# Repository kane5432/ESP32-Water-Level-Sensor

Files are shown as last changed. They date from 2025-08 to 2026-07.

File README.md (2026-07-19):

# Water Tank Level Monitor (ESPHome + Home Assistant)

If you found this project helpful, please consider supporting me:  

<a href="https://www.buymeacoffee.com/kanejarrats" target="_blank">Buy Me A Coffee</a>

This project uses an **ESP32‑C3** with an **ultrasonic sensor** to measure the water level in a tank, report the **fill percentage**, and **deep sleep** between readings to save power.  

It integrates with **Home Assistant**, storing the last known reading so you can still see the fill level even while the device is asleep.  

You can find the full blog post at https://jrattechworks.com/water-tank-level-sensor/

---

## Features
- Reads water tank level using an **AJ-SR04M** or similar ultrasonic sensor  
- Converts distance → **tank fill percentage**  
- **Deep sleep** between readings for extended battery life  
- **Persistent storage** in Home Assistant: keeps last known value when the ESP is offline  
- **OTA updates**: 2‑minute update window at each wake‑up for easy firmware flashing  

---

## Hardware
- **[ESP32‑C3 Super Mini](https://s.click.aliexpress.com/e/_c2uaIcnt)** (or compatible ESP32 board)  
- **[Ultrasonic Distance Sensor](https://s.click.aliexpress.com/e/_oocTPPV)** e.g. JSN‑SR04T or AJ-SR04M for waterproof applications)
- **[6V 1W Solar Panel](https://s.click.aliexpress.com/e/_onX79Zh)**
- **[TP4056 Charging Module](https://s.click.aliexpress.com/e/_omYIa87)**
- **[5v Boost Converter](https://s.click.aliexpress.com/e/_oBvVHe7)**
- **[470μF Capacitor](https://s.click.aliexpress.com/e/_oE1Fw4j)**
- **[1 kΩ + 2 kΩ resistors](https://s.click.aliexpress.com/e/_oFfpK9d)** (for voltage divider on echo pin)
- **[Wires](https://s.click.aliexpress.com/e/_oD4px7l) and a small enclosure** (optional but recommended)
- **[Soldering Iron](https://s.click.aliexpress.com/e/_c39TuVR5)**

## Wire the Ultrasonic Sensor to ESP32
- VCC → 5V (from boost converter)
- GND → GND
- Trigger → GPIO 3 (change in YAML if needed)
- Echo → Voltage divider (2 kΩ to Echo, 1 kΩ to GND, take signal from between resistors) → GPIO 2

### Why?
The sensor outputs 5V on Echo, but the ESP32 only tolerates 3.3V, the voltage divider drops it to a safe level.

## Wire the Power System
1. Solar panel → TP4056 input (IN+) & (IN–)
2. TP4056 output (BAT+ & BAT–) → Li‑ion battery
3. TP4056 output (BAT+ & BAT–) → Boost converter input
4. Boost converter output (5V & GND) → ESP32 5V pin and Ultrasonic sensor VCC
5. 470 µF capacitor across the boost converter output (helps prevent brown‑outs when ESP wakes up).

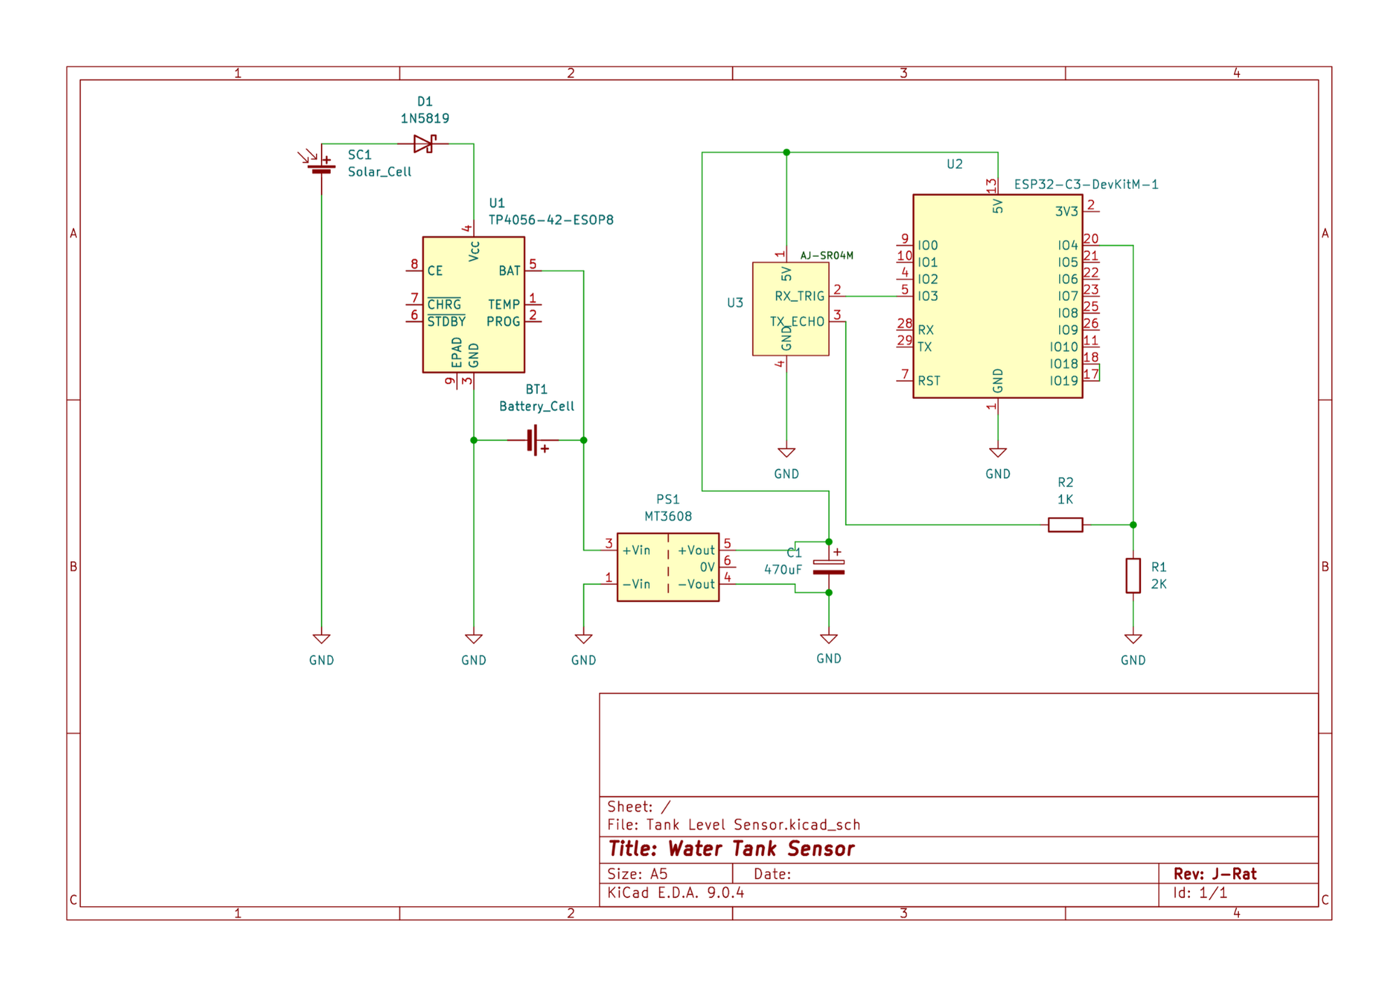
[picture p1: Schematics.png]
Schematic preview


---

## ESPHome Firmware
1. Copy the provided **`watertank-level.yaml`** file into your ESPHome directory (e.g., `esphome/watertank-level.yaml`).  
2. Replace the placeholders for Wi‑Fi credentials, API key, and OTA password.  
3. Adjust `max_distance` and `min_distance` in the YAML file to match your tank’s dimensions.  
4. Compile and flash the firmware to your ESP32 device using ESPHome.  

---

## Home Assistant Configuration
1. Open your `configuration.yaml`.  
2. Add the provided **input number** and **template sensor** sections for retaining the last known tank level.  
3. Restart Home Assistant to apply the changes.  

---

## Automation
1. Open your `automations.yaml`.  
2. Add the provided **automation** that updates the persistent tank level value whenever a new reading is received.  
3. Reload automations or restart Home Assistant.  

---

## Calibration
1. **Measure your tank’s depth when empty** → Set `max_distance` in the ESPHome file.  
2. **Measure the distance from the sensor to the water surface when full** → Set `min_distance`.  
3. **Flash the firmware** to your ESP device.  
4. **Monitor the ESPHome logs** to verify that readings are correct.  

---

## How it works
1. The ESP wakes up and connects to Wi‑Fi & Home Assistant API.  
2. It opens a **2‑minute OTA window** (can be changed in YAML) to allow firmware updates.  
3. The device takes a distance reading and converts it to a **fill percentage**.  
4. The reading is sent to Home Assistant.  
5. **If the reading succeeded:** the ESP goes into deep sleep for **1.5 hours**.  
6. **If the reading failed:** it retries after **1 minute**.

## Support this project
If you found this project helpful, you can support my work here:  



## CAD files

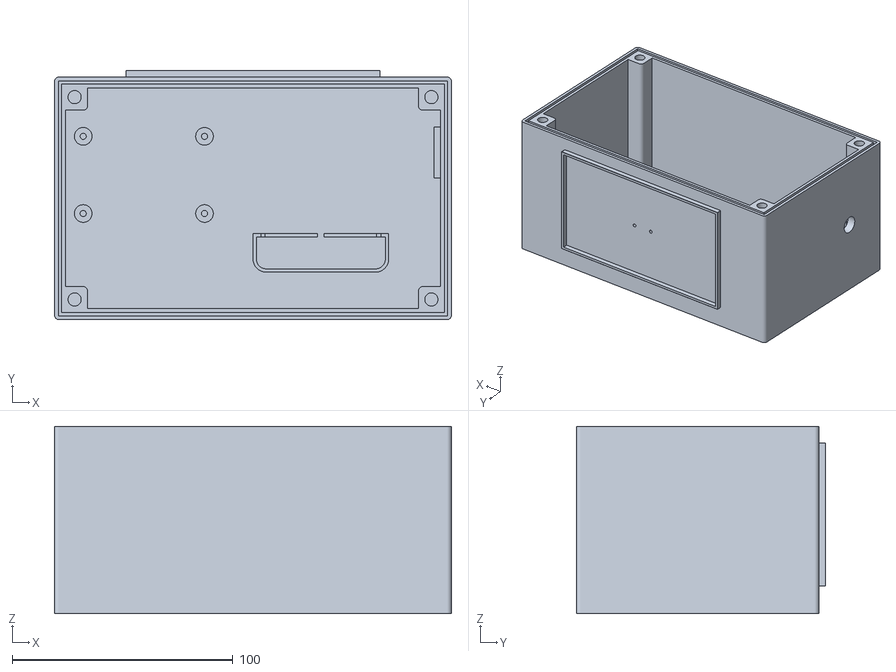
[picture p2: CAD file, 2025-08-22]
stl/WaterTankSensorBox-Body.stl
180.0 x 113.0 x 85.0

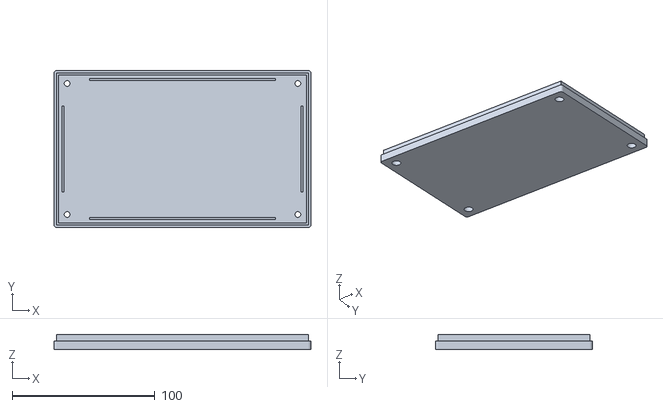
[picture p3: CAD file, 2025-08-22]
stl/WaterTankSensorBoxLid-Body.stl
180.0 x 110.0 x 10.7

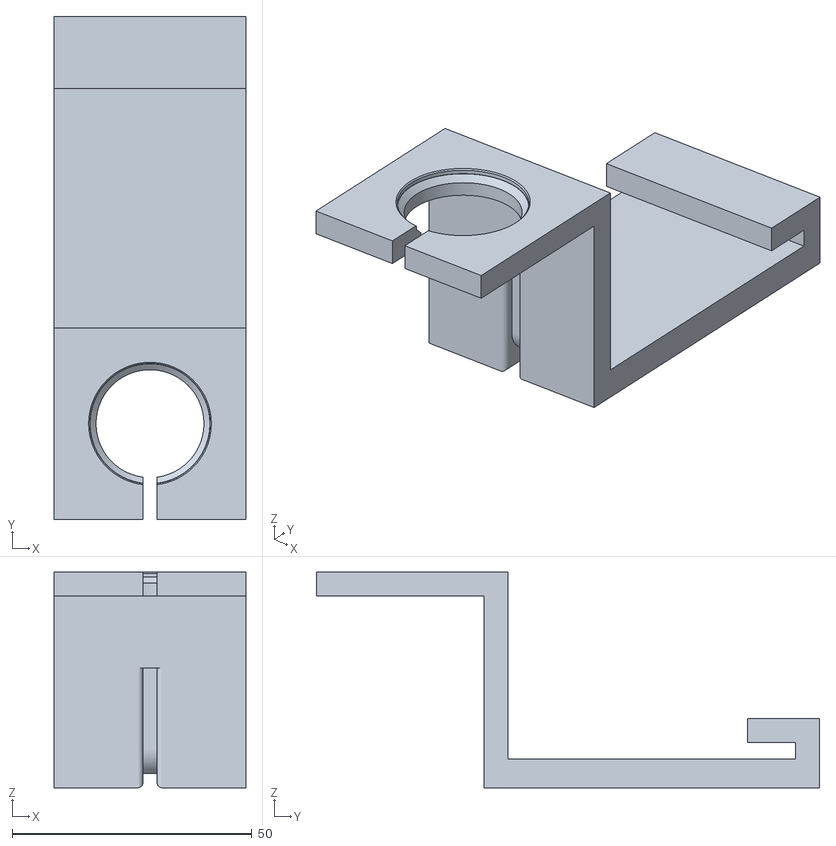
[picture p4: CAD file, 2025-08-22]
stl/UltrasonicHousing-BodySketch.stl
40.0 x 105.0 x 45.0

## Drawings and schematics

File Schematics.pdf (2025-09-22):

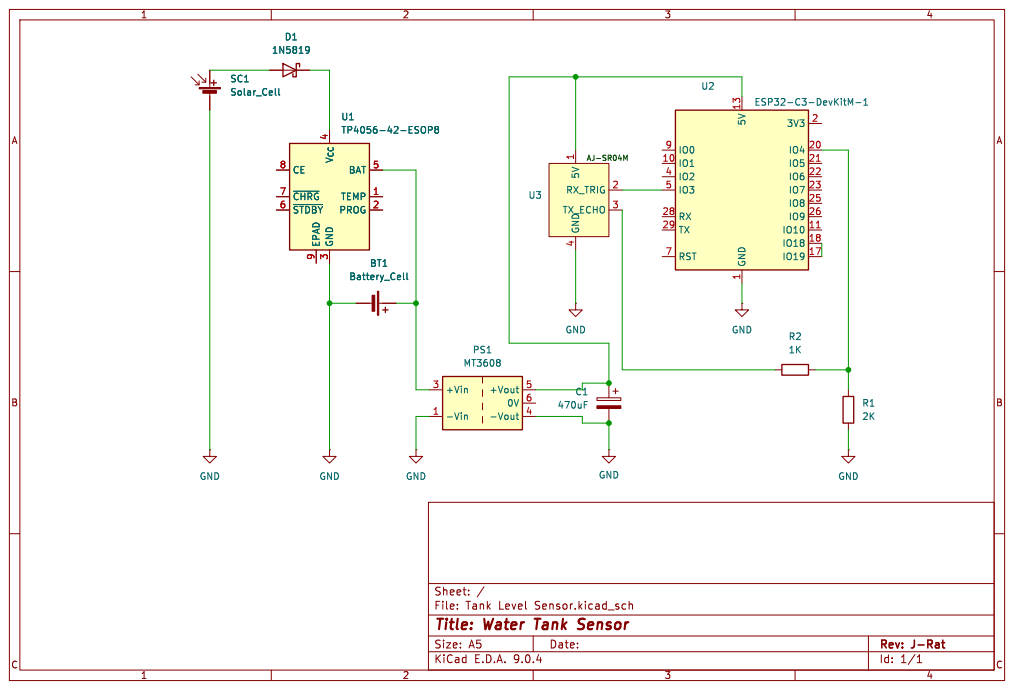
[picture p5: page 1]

3 BAT 5 TEMP 1 PROG 2 U1 TP4056-42-ESOP8 GND GND GND

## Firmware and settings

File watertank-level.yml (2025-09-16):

esphome:
  name: watertank-level
  friendly_name: watertank_level

  # On boot, wait for Wi-Fi & API, allow OTA window, take a reading, then deep sleep
  on_boot:
    priority: -100
    then:
      - wait_until:
          condition:
            wifi.connected
          timeout: 15s

      - delay: 120s  # OTA update window after Wi-Fi connects (adjust as needed)

      - wait_until:
          condition:
            api.connected
          timeout: 30s

      - if:
          condition:
            and:
              - wifi.connected
              - api.connected
          then:
            - delay: 2s
            - component.update: tank_distance  # Trigger distance measurement
            - delay: 20s  # Wait for reading to stabilize
            - if:
                condition:
                  lambda: 'return id(sensor_success);'
                then:
                  - deep_sleep.enter:
                      id: deep_sleep_ctrl
                      sleep_duration: 5400s  # Sleep for 1.5 hours after a good reading
                else:
                  - deep_sleep.enter:
                      id: deep_sleep_ctrl
                      sleep_duration: 60s  # Retry quickly if reading fails
          else:
            - deep_sleep.enter:
                id: deep_sleep_ctrl
                sleep_duration: 300s  # Retry in 5 minutes if Wi-Fi/API fail

esp32:
  board: esp32-c3-devkitm-1 # <-- Change depending on the board you're using
  framework:
    type: esp-idf

logger:
  baud_rate: 115200  # Serial log speed

api:
  encryption:
    key: "YOUR_API_KEY"  # <-- Replace with your API key

ota:
  platform: esphome
  password: "YOUR_OTA_PASSWORD"  # <-- Replace with your OTA password

wifi:
  ssid: "YOUR_WIFI_SSID"      # <-- Replace with your Wi-Fi SSID
  password: "YOUR_WIFI_PASSWORD"  # <-- Replace with your Wi-Fi password
  output_power: 15dB  # Adjust transmit power as needed (or remove for default)

captive_portal:

deep_sleep:
  id: deep_sleep_ctrl

# Global variable to track if the sensor reading succeeded
globals:
  - id: sensor_success
    type: bool
    restore_value: no
    initial_value: 'false'

sensor:
  # Ultrasonic sensor for distance measurement
  - platform: ultrasonic
    trigger_pin: GPIO4        # <-- Adjust these pins for your setup
    echo_pin: GPIO3
    name: "Tank Distance"
    id: tank_distance
    update_interval: never    # Only update when manually triggered
    timeout: 4.0m
    accuracy_decimals: 2
    unit_of_measurement: "m"
    filters:
      - median:
          window_size: 5      # Smooth readings with median filter
          send_every: 1
          send_first_at: 1
      - lambda: |-      # Remove |- if you're getting compilation errors on line 96, 97, 98
        // Ignore readings above 3m (beyond sensor/tank range)
        if (x > 3.0) return NAN;  
        return x;


    on_value:
      then:
        - if:
            condition:
              lambda: 'return !isnan(x);'
            then:
              - lambda: 'id(sensor_success) = true;'
        - component.update: tank_fill_level  # Update fill percentage

  # Template sensor to convert distance into fill percentage
  - platform: template
    name: "Tank Fill Level"
    id: tank_fill_level
    unit_of_measurement: "%"
    icon: "mdi:water-percent"
    accuracy_decimals: 1
    update_interval: never
    lambda: |-
      if (isnan(id(tank_distance).state)) {
        return NAN;  // Return no value if distance is invalid
      }

      float distance_cm = id(tank_distance).state * 100.0f;

      // --- USER CONFIGURABLE VALUES ---
      const float max_distance = 200.0f;  // Distance when tank is empty (in cm) - adjust!
      const float min_distance = 20.0f;   // Distance when tank is full (in cm) - adjust!
      // ---------------------------------

      if (distance_cm <= min_distance) {
        return 100.0f;  // Treat as full if at or below min
      }

      float filled = (max_distance - distance_cm) / (max_distance - min_distance) * 100.0f;

      if (filled < 0.0f) return 0.0f;
      if (filled > 100.0f) return 100.0f;
      return filled;

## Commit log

2025-08-22 Create stl
2025-08-22 Update stl
